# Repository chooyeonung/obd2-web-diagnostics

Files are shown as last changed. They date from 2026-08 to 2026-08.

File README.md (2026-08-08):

# ESP32 기반 차량 OBD-II 웹 진단 시스템

ESP32-S3 + CAN 트랜시버로 차량 OBD-II 포트에 연결하여, 브라우저(웹앱)에서 실시간 차량 진단(센서 모니터링, 고장코드 조회/소거)을 제공하는 시스템.

> **단계 전략**: ① 개인용 프로토타입 → ② 소량 검증(베타) → ③ 판매(제품화)
> 수익의 중심은 하드웨어가 아닌 **웹앱(서비스)**에 둔다. 통신 계층을 ELM327 표준으로 추상화해 "아무 동글이나 꽂아도 되는 진단 서비스"를 먼저 만들고, 자체 하드웨어는 프리미엄 옵션으로 추가한다.

---

## 1. 로드맵

### Phase 1 — 개인용 프로토타입 (지금)

목표: **내 차에서 내 웹앱으로 진단이 되는가?**

- [ ] 부품 구매 (아래 BOM)
- [ ] ELM327 호환 BLE 동글 1개 구매 (웹앱 선행 개발용, 쿠팡 1~3만 원 / 품질 원하면 vLinker MC+)
- [ ] 웹앱: Web Bluetooth로 동글 연결 → 표준 PID 조회(RPM, 냉각수온, 차속) 성공
- [ ] 하드웨어: 개발보드 + 모듈 결선(§4) → 벤치 테스트(CAN 루프백) → 차량 테스트
- [ ] 펌웨어: TWAI(CAN) 수신 → OBD-II 요청/응답 → WebSocket 전송
- [ ] 웹앱 트랜스포트 추상화: 동글(BLE)과 자작 보드(WebSocket) 모두에서 동일 동작 확인

### Phase 2 — 소량 검증 (10~50대)

목표: **다양한 차종에서 검증 + 커스텀 PCB화**

- [ ] KiCad로 아트웍 직접 설계 또는 크몽/설계사무소에 의뢰(2층, 부품 30~40개 → 설계비 약 30~80만 원)
- [ ] JLCPCB 등 PCBA로 소량 제작(이 수량대는 국내 턴키 대비 1/5~1/10 비용)
- [ ] WiCAN 공개 회로도를 전원부/보호회로 레퍼런스로 검토 (회로 참고 OK, 코드 복사 금지 — §7)
- [ ] 베타 사용자 확보: 차종별 진단 데이터 편차 수집 (이 사업의 실질 난이도)
- [ ] 절전 설계 검증: 딥슬립 + 전압 감시(배터리 방전 방지)

### Phase 3 — 판매 (제품화)

목표: **인증 통과 + 리스크 관리 + 양산**

- [ ] KC 전파인증(적합성평가): 완제품 기준 수백만 원. KC 인증된 ESP32-WROOM 모듈 사용으로 시험 범위 축소
- [ ] 배터리 방전 대책 최종화(대기전류 목표 < 1mA), ECU 영향 최소화(리스닝 우선 설계)
- [ ] 약관/면책 고지(차량 연결 기기 특성상 필수)
- [ ] 수백 대 이상 → 국내 턴키 업체(아이씨뱅큐, 샘플피씨비, 제이디앤테크놀로지 등) 견적 비교
- [ ] 펌웨어 라이선스 최종 점검(§7): GPL 코드 미포함 확인

---

## 2. BOM 및 구매처 (Phase 1)

| 부품 | 역할 | 구매처 | 확인가(2026-08) |
|---|---|---|---|
| ESP32-S3-WROOM-1 N8R2 개발보드 | MCU (TWAI/CAN 컨트롤러 내장, WiFi/BLE) | 디바이스마트 (VND032) | 약 14,850원 |
| SN65HVD230 CAN 모듈 (CJMCU-230) | CAN 트랜시버 (3.3V) | 제노몰 / 쿠팡 | 약 1,500~1,820원 |
| LM2596 DC/DC 모듈 (SZH-PWSD-001) | 차량 12V → 5V 강압 | 디바이스마트 | 약 1,650원 |
| SMAJ24A | 입력 서지(TVS) 보호 | 디바이스마트 | 약 1,925원 |
| OBD-II 16핀 Male 커넥터 | 차량 연결 | 쿠팡/네이버 국내배송 | 제품별 상이 |
| (추가) 폴리퓨즈 500mA~1A | 과전류 보호 | 디바이스마트 | 수백 원 |
| (추가) SS34 쇼트키 다이오드 | 역접속 보호 | 디바이스마트 | 수백 원 |
| (선택) PESD1CAN 또는 NUP2105L | CAN 라인 ESD 보호 | 디바이스마트 | 수백 원 |

### 부품별 주의사항

- **SN65HVD230 (CJMCU-230)**: 보드 위 **120Ω 종단저항(보통 R2)을 반드시 제거**할 것. 차량 CAN 버스는 이미 양단 종단되어 있음. 안 떼면 버스 임피던스가 무너져 통신 불안정/타 ECU 영향 가능.
- **LM2596**: 최대 입력 40V — 차량 로드덤프 서지에 마진이 빠듯하므로 SMAJ24A + 퓨즈 + 역접속 다이오드 필수. 무부하 대기전류가 수 mA라 **상시전원(핀 16)에 꽂아두면 배터리 방전 위험** → 장기적으로 저대기전류 레귤레이터 또는 딥슬립+하이사이드 스위치 검토.
- **OBD 커넥터**: "OBD2 16Pin **Male Plug + Shell + Solder/Terminal Pin**" 타입(차량 단자에 직결 + 후면 핀에 직접 배선). 단순 연장케이블 아님. 못 구하면 OBD2 연장케이블을 잘라 사용(테스터로 핀-선색 확인).

---

## 3. OBD-II 커넥터 핀맵 (사용 핀)

| OBD-II 핀 | 신호 | 연결 대상 |
|---|---|---|
| 4 | 섀시 GND | 공통 GND |
| 5 | 시그널 GND | 공통 GND (4번과 함께 묶음) |
| 6 | CAN-H (ISO 15765-4) | SN65HVD230 CANH |
| 14 | CAN-L (ISO 15765-4) | SN65HVD230 CANL |
| 16 | 배터리 +12V (상시) | 퓨즈 → 보호회로 → LM2596 IN |

나머지 핀(K-Line 7/15, J1850 2/10 등)은 Phase 1에서 미사용. CAN(ISO 15765-4)만으로 국내 2008년 이후 차량 대부분 커버(가솔린은 표준 PID 의무 구현).

---

## 4. 회로 결선도 (Phase 1, 모듈 조합)

```
OBD 16 (+12V) ──[폴리퓨즈 1A]──[SS34 ▶]──┬──[LM2596 IN+]
                                          │
                                     [SMAJ24A]   (단방향, 캐소드가 +12V 쪽)
                                          │
OBD 4,5 (GND) ────────────────────────────┴──[LM2596 IN-] ── 공통 GND

LM2596 OUT+ (5.0V로 조정) ──→ ESP32-S3 보드 5V(VIN) 핀
LM2596 OUT- ──→ GND

ESP32-S3 3V3 ──→ SN65HVD230 VCC (3.3V 전용 소자!)
ESP32-S3 GND ──→ SN65HVD230 GND

ESP32-S3 GPIO4 (TWAI TX) ──→ SN65HVD230 D (CTX)
ESP32-S3 GPIO5 (TWAI RX) ──→ SN65HVD230 R (CRX)

SN65HVD230 CANH ──→ OBD 6
SN65HVD230 CANL ──→ OBD 14
(선택) PESD1CAN을 CANH/CANL-GND 사이에 배치
```

### 결선 체크리스트

- [ ] LM2596 출력을 **부하 연결 전** 5.0V로 트리머 조정 (기본값이 높게 온다)
- [ ] SN65HVD230 모듈 120Ω 종단저항 제거 확인
- [ ] SMAJ24A 방향 확인 (단방향: 캐소드 밴드가 +12V 쪽)
- [ ] ESP32-S3에서 GPIO4/5는 TWAI에 자유 배치 가능(GPIO 매트릭스). 스트래핑 핀(GPIO0, 3, 45, 46)은 피할 것
- [ ] 차량 연결 전 벤치에서 12V 어댑터로 전원부 단독 검증
- [ ] (전압 감시용, 권장) 12V → 100k/10k 분압 → ESP32 ADC 핀: 시동 여부 감지(≈13.5V↑) 및 저전압 시 딥슬립

---

## 5. 펌웨어 아키텍처 (자체 작성)

> **처음부터 자체 작성한다.** wican-fw(GPL-3.0) 코드를 가져오면 제품화 시 소스 공개 의무 발생. Apache-2.0/MIT 스택만 사용(§7).

```
┌─────────────────────────────────────────┐
│  Web UI (LittleFS에 정적 파일로 탑재)      │
├─────────────────────────────────────────┤
│  HTTP 서버 + WebSocket (esp_http_server) │
│  WiFi SoftAP (초기) / STA (공유기 접속)    │
├─────────────────────────────────────────┤
│  ELM327 호환 명령 계층 (AT + PID 요청)     │  ← 웹앱과의 계약(contract).
├─────────────────────────────────────────┤     동글이든 자작보드든 동일 인터페이스
│  OBD-II 계층: SAE J1979 (Mode 01/03/04/09)│
│  ISO-TP (ISO 15765-2) 멀티프레임 조립      │
├─────────────────────────────────────────┤
│  TWAI 드라이버 (ESP-IDF, 500 kbps)        │
├─────────────────────────────────────────┤
│  전원 관리: ADC 전압 감시 → 딥슬립          │
└─────────────────────────────────────────┘
```

- 프레임워크: **ESP-IDF** (또는 Arduino-ESP32 코어) — 둘 다 Apache-2.0
- CAN 설정: 500 kbps, 11bit ID 기본(요청 0x7DF, 응답 0x7E8~0x7EF). 일부 차량 29bit(0x18DB33F1) 폴백
- 진단 기능 우선순위: Mode 01(실시간 데이터) → Mode 03(DTC 조회) → Mode 04(DTC 소거) → Mode 09(VIN)
- **웹앱 서빙은 ESP32에서 직접**(LittleFS): 외부 HTTPS 호스팅 시 브라우저 혼합 콘텐츠 정책으로 ws:// 연결이 차단됨
- 안전 원칙: 기본은 **수신 전용**에 가깝게, 전송은 표준 진단 요청만. 임의 CAN 주입 기능은 제품에서 제외

## 6. 웹앱 아키텍처

```
┌───────────────────────────────────────────────┐
│  UI: 대시보드(게이지/차트), DTC 목록·해설, 로그   │
├───────────────────────────────────────────────┤
│  도메인 계층: PID 디코딩 테이블(J1979),          │
│              DTC 데이터베이스(P0xxx 해설)        │
├───────────────────────────────────────────────┤
│  프로토콜 계층: ELM327 명령 생성/응답 파싱        │
├───────────────────────────────────────────────┤
│  트랜스포트 추상화 (인터페이스 1개, 구현 2개)      │
│   ├─ WebSocket  ← 자작 ESP32 보드              │
│   └─ Web Bluetooth(BLE) ← 시판 ELM327 동글      │
└───────────────────────────────────────────────┘
```

- **트랜스포트 추상화가 핵심**: Phase 1에서 동글로 개발한 코드가 자작 보드·WiCAN·향후 자체 제품까지 그대로 재사용됨
- Web Bluetooth는 Chrome/Edge 지원(iOS Safari 미지원 — iOS 대응 필요 시 WebSocket 경로 사용)
- 오프라인 대응: PWA(서비스워커)로 구성하면 지하주차장 등 무네트워크 환경에서도 동작
- 참고 프로젝트: EQM_OBDWEB(ESP32 웹 대시보드 서빙 사례), ELMduino(MIT, PID 파싱 참고), obd-ble-serial(BLE 연결 사례)

---

## 7. 라이선스 전략

| 자산 | 라이선스 | 사용 방침 |
|---|---|---|
| wican-fw 펌웨어 코드 | GPL-3.0 | **코드 복사/개조 금지** (제품화 시 소스 공개 의무 발생). 기능 아이디어 참고만 |
| WiCAN 회로도 (sch/) | GPL-3.0 (저장소) | 회로 토폴로지(설계 개념) 참고는 가능. 파일 자체를 복제·배포하지 않음. Phase 2에서 자체 설계로 재작성 |
| ESP-IDF / Arduino-ESP32 | Apache-2.0 / LGPL | 사용 OK |
| ELMduino | MIT | 사용 OK (파싱 로직 참고/포함 가능) |
| 자체 펌웨어·웹앱 | 자체 결정 | 비공개 유지 가능하도록 GPL 코드 미포함 원칙 유지 |

## 8. 인증·판매 리스크 체크리스트 (Phase 3)

- [ ] **KC 적합성평가(전파인증)**: WiFi/BLE 탑재 완제품은 필수. KC 인증 완료된 ESP32-WROOM 모듈 채택 시 시험 범위 축소되나 완제품 등록은 별도. 예산 수백만 원 단위
- [ ] **배터리 방전**: 상시전원 사용 시 대기전류 스펙 명시(목표 <1mA), 저전압 컷오프 필수
- [ ] **ECU 안전성**: 표준 진단 요청 외 전송 금지, DTC 소거는 사용자 확인 2단계
- [ ] **면책 고지**: 차량 보증/AS 관련 분쟁 대비 약관 명시
- [ ] **경쟁 구도**: 하드웨어 단품은 중국산 저가 동글과 가격 경쟁 불가 → 웹앱 구독/서비스 모델로 차별화
- [ ] **GPL 오염 검사**: 배포 전 펌웨어 의존성 라이선스 전수 확인

---

## 9. 참고 자료

- WiCAN (오픈소스 ESP32 OBD 동글): <https://github.com/meatpiHQ/wican-fw> — 회로 레퍼런스, GPL 주의
- WiCAN Pro (전 프로토콜 지원 상위판, $89): <https://www.crowdsupply.com/meatpi-electronics/wican-pro>
- ELMduino (MIT, ELM327/OBD 파싱): <https://github.com/PowerBroker2/ELMduino>
- EQM_OBDWEB (ESP32 웹 OBD 대시보드): <https://github.com/EQMOD/EQM_OBDWEB>
- obd-ble-serial (Web BLE 연결 예제): <https://github.com/vdvornichenko/obd-ble-serial>
- 국내 PCB/SMT: 아이씨뱅큐 <https://www.icbanq.com/pcb>, 샘플피씨비 <http://www.samplepcb.co.kr/>, PCB아트웍스 <https://pcbartworks.co.kr/>
- 해외 PCBA: JLCPCB <https://jlcpcb.com/>

---

*작성: 2026-08-08 · Phase 1 진행하며 실측값/차종 테스트 결과를 이 문서에 갱신할 것*

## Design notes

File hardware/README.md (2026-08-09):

# hardware/ — KiCad 회로도

`obd2-gateway.kicad_sch` — 벤치 회로(모듈 단위)의 KiCad 회로도.
KiCad 7 이상에서 열림 (독립 파일이라 프로젝트 없이 더블클릭으로 열려요).

- 연결은 **같은 이름의 부품 사이를 실제 배선(wire)으로 연결한 전통적 스타일 — 선을 따라가며 읽으면 됩니다
- 심볼은 자체 라이브러리(OBD2DIY)로 파일 안에 내장 — 별도 라이브러리 설치 불필요
- 향후 캐리어 보드 아트웍 시 이 회로도에 풋프린트를 지정하고 PCB로 넘기면 됨

kicad-cli 7.0.11로 파싱/SVG 출력 검증 완료.

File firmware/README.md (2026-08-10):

# OBD-II WiFi 게이트웨이 펌웨어 (ESP32-S3)

브라우저 ←WiFi/WebSocket→ **[이 펌웨어: ELM327 에뮬레이션]** ←CAN(TWAI)→ 차량 ECU

웹앱의 `WebSocketTransport`와 대화 규격이 맞춰져 있어, 플래시 후 웹앱에서
"자작 보드 (WiFi/WebSocket)" 트랜스포트로 바로 연결된다. Safari/iPhone도 이 경로로 커버.

## 결선 (구매 부품 기준)

| ESP32-S3 (VND018) | 연결 대상 |
|---|---|
| GPIO17 (J3 핀10) | SN65HVD230 **D** (CTX) |
| GPIO18 (J3 핀11) | SN65HVD230 **R** (CRX) |
| 3V3 | SN65HVD230 VCC |
| GND | SN65HVD230 GND, LM2596 OUT- |
| 5V(VIN) | LM2596 OUT+ (**5.0V로 조정 후 연결**) |

- SN65HVD230 CANH → OBD 6번 핀, CANL → OBD 14번 핀
- 전원: OBD 16번(+12V) → 폴리퓨즈 → SS34 → SMAJ24A/P6KE24A(병렬) → LM2596 IN+
- **CJMCU-230 모듈의 120Ω 종단저항(R2) 제거 필수**

## 빌드 & 플래시

[ESP-IDF 5.x](https://docs.espressif.com/projects/esp-idf/en/stable/esp32s3/get-started/) 설치 후 (VS Code ESP-IDF 확장 권장):

```bash
cd firmware
idf.py set-target esp32s3
idf.py build          # web/ 폴더가 LittleFS 이미지로 자동 포함됨
idf.py -p COM포트 flash monitor
```

## 사용

1. 부팅 후 WiFi **`OBD2-DIAG`** (비밀번호 `obd12345`) 접속
2. 브라우저에서 `http://192.168.4.1/` → 내장 테스트 콘솔 (ATZ, 010C 등 즉시 테스트)
3. 본 웹앱에서는 WebSocket 주소 `ws://192.168.4.1/ws` 로 연결

## 벤치 테스트 순서 (차량 연결 전)

1. USB 전원만으로 부팅 → WiFi 접속 → 콘솔에서 `ATZ` 응답 확인 (CAN 없이도 동작)
2. `010C` → CAN 미연결 상태면 `NO DATA` (정상 — 타임아웃 경로 확인)
3. 트랜시버 연결 + CAN 분석기(또는 두 번째 보드)로 루프백 응답 테스트
4. 차량 연결: OBD 커넥터 결선 후 `010C` → `41 0C xx xx` 응답 확인

## 구조

```
main/
  twai_bus.c   TWAI(CAN) 드라이버 — 500kbps, 0x7E8~0x7EF 수신 필터
  obd.c        ISO-TP 최소 구현 (SF 요청, SF/FF+CF 응답 조립, Flow Control)
  elm327.c     ELM327 호환 명령 파서 (AT 설정 + OBD hex 패스스루)
  wifi_ap.c    SoftAP (OBD2-DIAG / 192.168.4.1)
  ws_server.c  WebSocket(/ws) + LittleFS 정적 서빙(웹 콘솔)
web/           LittleFS로 플래시되는 정적 파일 (테스트 콘솔)
```

## TODO

- [ ] BLE(ELM327 에뮬레이션) 듀얼 모드 — 안드로이드/데스크톱 크롬 직결용
- [ ] ADC 전압 감시 (ATRV 실측값 + 저전압 딥슬립)
- [ ] STA 모드 설정 UI (공유기 접속 옵션)
- [ ] OTA 업데이트
- [ ] Blazor 웹앱 publish 산출물을 web/에 넣어 self-hosting (선택)

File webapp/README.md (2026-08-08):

# OBD-II 웹 진단 — Blazor WASM 웹앱

vLinker MC+ (ELM327 호환 BLE 동글) 또는 내장 시뮬레이터로 차량 진단을 수행하는 Blazor WebAssembly 앱.

## 실행 방법

```bash
cd webapp
dotnet run
```

브라우저에서 `http://localhost:5000` (콘솔에 표시되는 포트) 접속.

- **시뮬레이터 모드**: 동글/차량 없이 바로 동작. 가상 ECU가 주행 데이터와 고장코드(P0133, P0420)를 흉내낸다.
- **BLE 모드**: Chrome/Edge에서만 동작(Web Bluetooth). vLinker MC+ 전원이 켜진 상태(차량 OBD 포트 연결)에서 "연결" 클릭 → 기기 선택.
  - Web Bluetooth는 **HTTPS 또는 localhost**에서만 동작한다. 외부 배포 시 HTTPS 필수.

## 구조

```
Services/
  IObdTransport.cs      트랜스포트 추상화 (시뮬레이터/BLE/향후 WebSocket 공용 인터페이스)
  SimulatorTransport.cs 가상 ELM327+ECU (실차 없이 전체 흐름 테스트)
  BleTransport.cs       Web Bluetooth JS interop 래퍼
  Elm327Client.cs       ELM327 대화 규칙 (명령 → '>' 프롬프트까지 응답 수집, 초기화 시퀀스)
  ObdService.cs         고수준 진단 API (PID 스냅샷, DTC 조회/소거, VIN) + 응답 파서
  PidDefinitions.cs     SAE J1979 Mode 01 PID 테이블 (여기 추가하면 UI 자동 반영)
  DtcDecoder.cs         DTC 2바이트 → P/C/B/U 코드 + 한글 설명
wwwroot/js/obd-ble.js   Web Bluetooth 모듈 (프레임워크 독립 — 향후 ESP32용 경량 페이지에 재사용)
Pages/Home.razor        대시보드 (연결/게이지/DTC/통신 로그)
```

## 설계 노트

- **트랜스포트 추상화**가 핵심: 자작 ESP32 보드가 완성되면 `WebSocketTransport`를 `IObdTransport`로 추가하기만 하면 나머지 계층은 그대로 동작한다. ESP32 펌웨어가 ELM327 명령을 에뮬레이션하는 것이 전제.
- DTC 소거(Mode 04)는 되돌릴 수 없는 동작이라 2단계 클릭 확인을 거친다.
- 응답 파서는 실차의 흔한 변형(SEARCHING 프리픽스, 멀티라인 응답, ISO-TP 프레임 인덱스 `0:`, NO DATA)에 관대하게 동작하도록 작성했다.

## 다음 단계 (TODO)

- [ ] 실차(vLinker MC+)에서 BLE 연결·PID 폴링 검증
- [ ] Mode 02(프리즈 프레임), Mode 07(미확정 DTC) 추가
- [ ] 시계열 차트(주행 로그) 및 기록 저장
- [ ] PWA 구성(오프라인 동작)
- [ ] 자작 ESP32 보드용 WebSocketTransport 추가

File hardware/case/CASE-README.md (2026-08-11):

# OBD_CAN_ESP32_V2 케이스 (초안 v1)

외형 약 78.4 × 42.4 × 30mm · 상하 2피스 · M2.5 나사 4개로 리드+PCB+베이스 동시 체결

## 구조

- **베이스**: PCB가 나사 보스 4개(높이 8.5mm) 위에 안착. 뒷면 부품(D1·Q1·TP)과
  J1 커넥터 공간 확보. 오른쪽 벽에 J1 케이블 개구 + 커넥터 하우징 받침 턱
  (케이블을 뽑을 때 힘이 납땜부가 아닌 케이스에 걸리도록)
- **리드**: 분리면 = PCB 윗면. 오른쪽 벽에 USB-C 개구(데브킷 플래시/디버깅용),
  상단에 벅 컨버터 방열 슬롯 + **RGB LED 상태표시 창**(⌀5, 바깥으로 벌어지는
  원뿔형이라 비스듬히 봐도 보임). 나사 기둥이 PCB를 위에서 눌러 고정
- LED 색 규칙(펌웨어): 파랑 숨쉬기=대기, 초록 깜빡=통신, 주황=CAN오류, 보라=OTA
- **왼쪽 내부 5mm 여유**: 데브킷 WROOM 안테나 돌출 공간 (금속 부착 금지)
- 조립: M2.5 × 25mm 접시머리 나사 4개가 리드 → PCB 구멍(2.7mm) → 베이스 보스(셀프태핑) 순으로 관통

## 실측 후 조정할 파라미터 (obd2_case.scad 상단)

| 파라미터 | 현재값(추정) | 실측 방법 |
|---|---|---|
| `H_BOT` | 8.5 | 보드 뒷면에서 J1 하우징 바닥까지 + 1mm |
| `H_TOP` | 16 | PCB 윗면에서 데브킷 최고점(USB 커넥터)까지 + 2mm |
| `USB_Z0`/`USB_Z1` | 9.5/15.5 | PCB 윗면 기준 데브킷 USB-C 상하 위치 |
| `USB_Y0`/`USB_Y1` | 7/29 | 두 USB-C 포트의 좌우 범위 |
| `LED_X`/`LED_Y` | 52/17.5 | 데브킷 RGB LED 위치 (보드 좌하단 기준). 데브킷 장착 후 위에서 내려다보며 실측 |

값 수정 → OpenSCAD에서 열기 → part="base"/"lid"로 각각 STL 내보내기.

## 출력 가이드

- 재질: **PETG / ABS / PA12(나일론)** — 차량 실내 온도 때문에 PLA 금지
- 방향: 베이스·리드 모두 개구부가 위로 오게(뒤집힌 상태 그대로) 출력, 서포트 불필요
  (USB/J1 개구는 브리지 15mm 이하라 서포트 없이 출력됨)
- 레이어 0.2mm, 벽 3라인, 인필 20%+
- JLC3DP 주문 시: PA12(MJF) 회색 권장

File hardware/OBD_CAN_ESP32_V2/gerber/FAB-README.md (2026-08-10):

# OBD_CAN_ESP32_V2 — 발주 안내

## 보드 사양 (JLCPCB 주문 시 입력값)

| 항목 | 값 |
|---|---|
| 치수 | 64 × 36 mm |
| 층수 | 2 |
| 두께 | 1.6 mm |
| 구리 두께 | 1 oz |
| 표면처리 | HASL(무연) 또는 ENIG |
| 최소 트랙/간격 | 0.20 / 0.20 mm |
| 최소 드릴 | 0.20 mm (U2 열비아 6개, 패드경 0.50 mm) |
| 비아 | 0.60 / 0.30 mm |
| 나사구멍 | 2.7 mm NPTH × 4 (M2.5) |
| 총 홀 수 | 83 |
| 안테나 구리 금지 | 왼쪽 끝 5mm 폭 (양면) — 데브킷 WROOM 안테나 하부 |

## 파일 구성

| 파일 | 용도 |
|---|---|
| `*-F_Cu.gbr` / `*-B_Cu.gbr` | 앞면/뒷면 구리 |
| `*-F_Mask.gbr` / `*-B_Mask.gbr` | 솔더마스크 |
| `*-F_Silkscreen.gbr` / `*-B_Silkscreen.gbr` | 실크스크린 |
| `*-Edge_Cuts.gbr` | 보드 외형 |
| `*.drl` | 드릴 (PTH/NPTH 병합, 엑셀론) |
| `*-job.gbrjob` | 거버 잡 파일 |
| `BOM-jlcpcb.csv` | 부품 목록 (LCSC 번호 포함) |
| `CPL-jlcpcb.csv` | 부품 좌표 (SMT 조립 주문 시) |
| `*-top-pos.csv` / `*-bottom-pos.csv` | KiCad 원본 좌표 파일 |

## 발주 순서

1. jlcpcb.com → **Order now** → 위 zip 업로드
2. 미리보기에서 64×36mm, 2층, 앞/뒷면 패턴 확인
3. 층수 2 / 두께 1.6 / 표면처리 선택
4. **직접 납땜하는 경우: SMT 조립 끄기** → 여기서 끝
5. SMT 조립을 맡기는 경우 → BOM·CPL 업로드 → 부품 확인 화면에서 회전값 검토

## 주문 전 확인할 것

- **Q1 부품 확정**: 회로도 값이 `Q_PMOS_GDS`(범용 심볼)입니다. BOM에는 SUD50P06-15-GE3(C141584)을 넣어뒀습니다. 저렴한 대안은 HYG120P06LR1D(C2844410). 회로도 값도 실제 품번으로 바꿔두세요.
- **R3는 실장 금지(DNP)**: 차량 CAN 버스에 이미 종단저항이 있습니다. CPL에서 제외했습니다.
- **J3/J4 헤더**: 데브킷을 꽂을 암헤더(2.54mm 1×22) 2개는 BOM에 품번을 넣지 않았습니다. 직접 구매하세요.
- **D1(SM8S24A) 재고**: LCSC 재고가 1,000개 미만이고 제조사별로 가격이 3배까지 차이납니다. 주문 시점에 확인 필요.
- **R12(182k) 재고**: 모든 소스가 5,000개 미만입니다. 부족하면 C163428(Yageo) 또는 180k로 대체 가능(스위칭 주파수 약 505kHz로 미세 변동).
- **L1 Isat 3.5A**: 계획서에는 4A로 적었지만 실제 부하는 0.8A 이하이므로 충분합니다.

## 조립 시 참고

- 부품 위치는 `docs/assembly-front.svg` / `docs/assembly-back.svg` 참조 (실크스크린에 참조번호가 없습니다)
- 뒷면 대형 부품(D1 TVS, Q1 MOSFET, J1 커넥터)을 먼저, 앞면 SMD를 나중에
- U2 열패드는 뒷면 열비아 6개를 통해 인두로 납을 흘려넣을 수 있습니다
- **J1 커넥터 몸통이 보드 오른쪽으로 6.8mm 돌출**합니다. 케이스에서 몸통을 받쳐주도록 설계하세요.

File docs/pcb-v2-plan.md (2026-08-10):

# PCB V2 계획 — C안: 온보드 벅 + 데브킷 하부 배치 (목표 66×36mm)

V1(69×72) 대비 면적 −56%. 핵심: LM2596 모듈 제거 → SMD 벅 회로, 모든 SMD를 데브킷 아래(헤더 사이 22.86mm 폭, 높이 여유 ~8.5mm)로.

## 1. 벅 컨버터 회로 (LM2596 모듈 대체)

**IC: TI TPS54360B** (SO-8 PowerPAD) — 입력 4.5~**60V**, 3.5A, 비동기 벅.
60V 내압이라 SM8S24A 클램핑 전압(~39V)과 로드덤프에 마진 충분. LCSC/JLC 재고 안정.

| Ref | 값/부품 | 패키지 | 비고 |
|---|---|---|---|
| U2 | TPS54360BDDA | SO-8 PowerPAD | 열패드 → GND 비아 4개 이상 |
| C10,C11 | 2.2µF 100V X7R ×2 | 1210 | VIN 입력 (VBAT_PROTECTED) |
| C12 | 100nF 100V | 0805 | VIN 고주파 |
| C13 | 100nF 25V | 0603 | BOOT–SW |
| D10 | B360A (60V 3A 쇼트키) | SMA | 캐치 다이오드, SW–GND |
| L1 | 10µH 4A 실드형 (예: SWPA6045S100MT) | 6.0×6.0×4.5mm | SW → VOUT |
| C14,C15 | 22µF 16V X7R ×2 | 1206 | 출력 (+5V) |
| R10 | 52.3kΩ 1% | 0603 | FB 상단 (VOUT→FB) |
| R11 | 10.0kΩ 1% | 0603 | FB 하단 (FB→GND) → 5.0V |
| R12 | 182kΩ 1% | 0603 | RT/CLK → GND, fsw≈500kHz |
| R13 | 8.06kΩ | 0603 | COMP 직렬 R |
| C16 | 3300pF | 0603 | COMP 직렬 C (R13와 직렬로 COMP→GND) |
| R14/R15 | 365k / 88.7k (선택) | 0603 | EN 분압 — UVLO ≈8.6V 시작 (크랭킹 채터 방지). 생략 시 EN 플로팅 |

- 배선: VIN 루프(C10/C11–IC–D10) 최소화, SW 노드 면적 최소, FB 트레이스는 L/SW에서 멀리
- VOUT(+5V) → 데브킷 5V 핀(J3-21), 부하 여유: ESP32 WiFi 피크 ~0.6A ≪ 3.5A
- 점유 면적 ≈ 18×16mm → 데브킷 하부 수납 가능 (최대 높이 L1 4.5mm < 8.5mm)

## 2. 보드 구성 (66×36)

```
 ← 66mm →
┌────────────────────────────────────────────┐
│ [안테나 돌출/구리금지 8mm]   ESP32-S3 DevKitC   [USB 엣지] │ ↑
│ ┌헤더row───────────────────────헤더row┐      │ 36mm
│ │  (하부) CAN존 │ 벅존 │ 입력보호존        │      │
│ └──────────────────────────────────┘      │
│ [JST-XH 6P]  [TP열 1.5mm]                  │ ↓
└────────────────────────────────────────────┘
```

- **데브킷 방향**: 안테나(WROOM 끝) = 보드 왼쪽 **엣지 밖으로 2~3mm 돌출** 또는 그 영역 전층 구리 금지. USB 커넥터 = 오른쪽 엣지에 맞춤(케이블 접근)
- **하부 존 배치** (모두 높이 ≤4.5mm라 간섭 없음):
  - 입력보호존(USB쪽 끝): F1(1812) → SM8S24A → Q1(TO-252) + R1 + D2
  - 벅존(중앙): 위 1번 회로
  - CAN존(커넥터쪽): U1 + C1(U1 VCC 2mm 이내!) + R2 + R3(DNP)
- **커넥터**: 터미널블록 → **JST-XH 6P 사이드엔트리**(S6B-XH-A, 16.5×7mm) 하단 긴 변 엣지. D3(NUP2105L)는 커넥터 3mm 이내
- **TP**: D1.5mm SMD 패드로 축소, 하단 스트립에 일렬
- CAN_H/L: 차동 페어로 커넥터→D3→U1 최단 라우팅, 스터브 최소

## 3. V1에서 가져갈 수정사항

- [ ] **D2 제너 180° 반전** (K→VBAT_PROTECTED/소스, A→게이트) — V1 치명 이슈
- [ ] C1을 U1 VCC 핀 옆으로
- [ ] CAN_TX/RX = J3 핀10/11 = **GPIO17/GPIO18** (DevKitC-1 공식 핀맵 기준 — 실물 실크로 최종 확인)
  → 펌웨어 `twai_bus.h` GPIO17/18로 변경 완료. 모든 문서도 17/18로 통일함

## 4. 발주 체크 (JLCPCB 기준)

- 2층, 1oz, 보드 66×36, 최소 트랙/갭 0.2mm면 충분
- TPS54360B·B360A·인덕터는 LCSC 파트넘버로 BOM 지정 (SMT 조립 시)
- 데브킷 헤더는 스루홀 → 이코노미 SMT + 수납땜 또는 스탠다드 조립

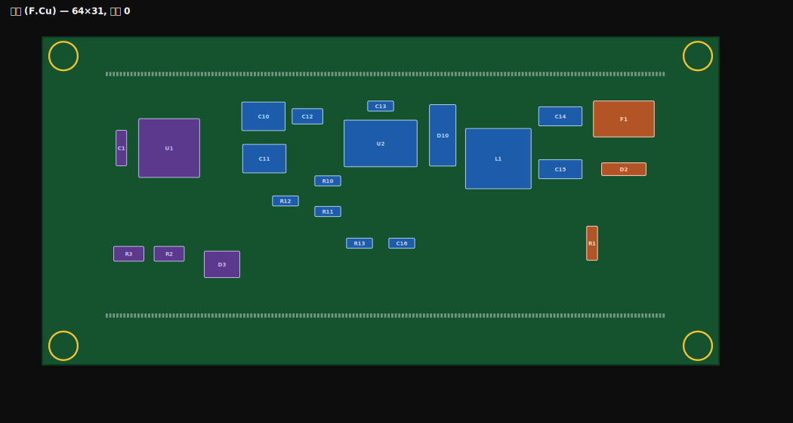
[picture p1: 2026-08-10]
hardware/OBD_CAN_ESP32_V2/front-preview.png

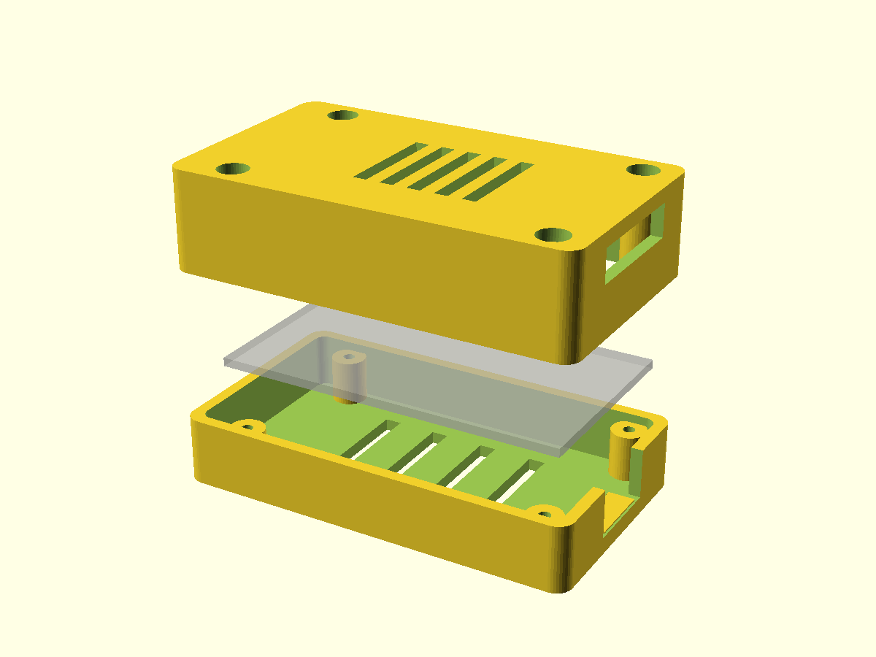
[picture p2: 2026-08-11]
hardware/case/preview_exploded.png

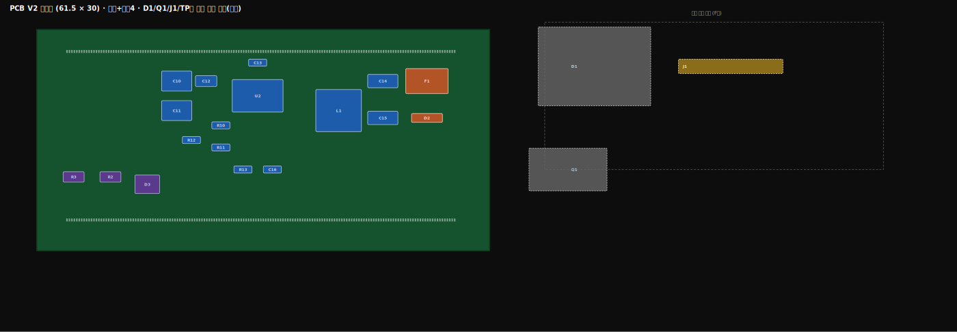
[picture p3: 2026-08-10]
hardware/OBD_CAN_ESP32_V2/placement-preview.png

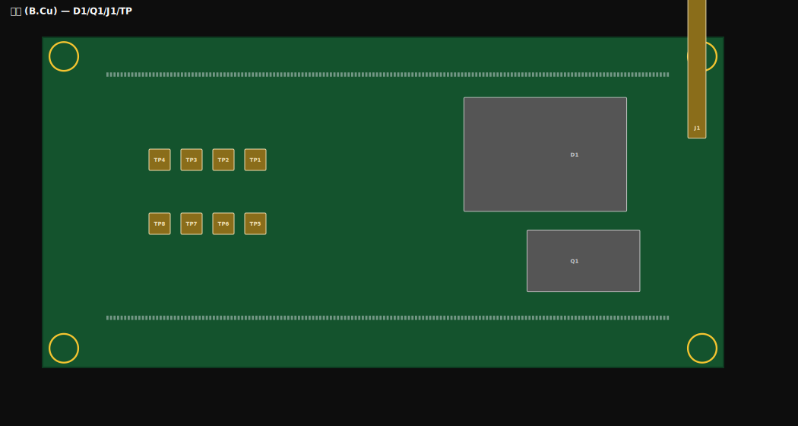
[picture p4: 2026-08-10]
hardware/OBD_CAN_ESP32_V2/back-preview.png

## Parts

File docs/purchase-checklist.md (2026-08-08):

# Phase 1 부품 구매 체크리스트

작성일: 2026-08-08 · 예상 총 예산: **약 3~4만 원** (+ ELM327 동글 1~3만 원)

## 디바이스마트 (한 번에 주문)

| # | 부품 | 검색 키워드 | 수량 | 단가(참고) | 확인 포인트 |
|---|---|---|---|---|---|
| ☐ | ESP32-S3 개발보드 | `ESP32-S3-WROOM-1 N8R2` (상품코드 VND032) | 1 | 약 14,850원 | N8R2(8MB Flash/2MB PSRAM) 맞는지, USB-C 2포트(USB/UART) 타입 권장 |
| ☐ | LM2596 DC/DC 모듈 | `LM2596 SZH-PWSD-001` | 2 | 약 1,650원 | **가변(트리머)형**인지 확인 — 고정 3.3V/5V 출력형 아님 |
| ☐ | SMAJ24A TVS | `SMAJ24A` | 5 | 약 1,925원/개 또는 소포장 | **단방향(uni)** 확인. 최소구매수량 체크 |
| ☐ | 폴리퓨즈 1A | `폴리퓨즈 1A 리드타입` | 5 | 수백 원 | 정격전압 30V 이상 (예: RXEF 시리즈) |
| ☐ | 쇼트키 다이오드 | `SS34` 또는 `1N5822` | 5 | 수백 원 | 3A/40V급, 역접속 보호용 |
| ☐ | (선택) CAN ESD 보호 | `PESD1CAN` 또는 `NUP2105L` | 2 | 수백 원 | SOT-23 SMD라 변환기판 필요할 수 있음 — 없으면 생략 가능 |
| ☐ | 소모품 | 점퍼선(F-F/M-F), 만능기판, 수축튜브, 2.54mm 핀헤더 | — | ~5,000원 | 없으면 같이 주문 |

## 제노몰

| # | 부품 | 검색 키워드 | 수량 | 단가(참고) | 확인 포인트 |
|---|---|---|---|---|---|
| ☐ | SN65HVD230 CAN 모듈 | `SN65HVD230 CAN Module` | **2~3** | 약 1,500원 | 보드 사진에서 **120Ω 저항(R2) 위치 확인**(도착 후 제거해야 함). 예비 포함 2~3개 권장 |

배송비 고려해서 SN65HVD230도 쿠팡(약 1,820원)으로 합쳐도 무방 — 합계 차이는 몇백 원.

## 쿠팡 / 네이버쇼핑

| # | 부품 | 검색 키워드 | 수량 | 확인 포인트 |
|---|---|---|---|---|
| ☐ | OBD-II Male 커넥터 | `OBD2 16핀 male 커넥터 납땜` / `OBD2 male plug 하우징 터미널` | **2** | 아래 "OBD 커넥터 고르는 법" 필독 |
| ☐ | ELM327 BLE 동글 (웹앱 선행 개발용) | `vLinker MC+` (권장) 또는 `ELM327 v1.5 블루투스 4.0` | 1 | **BLE(블루투스 4.0+) 필수** — Web Bluetooth는 클래식 BT 미지원. iOS 지원 표기 = BLE라는 신호 |

### OBD 커넥터 고르는 법 (잘못 사면 잘라서 배선해야 함)

사진에서 반드시 확인:

1. **Male(수) 커넥터** — 차량 포트에 꽂히는 쪽. 사다리꼴 16핀 돌출형
2. **뒷면이 열리는 하우징(Shell)** + **납땜 가능한 터미널 핀** 구성 — "플러그 + 쉘 + 솔더핀" 세트
3. 케이블이 이미 몰딩된 일체형(연장케이블류)은 ✗ — 이건 잘라야 함
4. 대안: 검색어 `OBD2 커넥터 조립식` / `OBD2 male DIY 커넥터`
5. 정 못 찾으면 차선책으로 OBD2 연장케이블(수-암)을 사서 절단 — 테스터로 핀 4,5,6,14,16 대응 선색 확인

### ELM327 동글 참고

- 최우선: **vLinker MC+** (FORScan 등에서 검증된 안정성, 3만 원대) — 국내 재고 없으면 알리익스프레스
- 차선: 국내배송 "ELM327 V1.5 PIC18F25K80 블루투스 4.0 (BLE)" 표기 제품 — V2.1 표기나 칩 미표기 초저가는 호환성 문제 잦음
- 용도: 자작 보드 완성 전까지 웹앱(Web Bluetooth) 개발·차량 테스트용

## 주문 후 도착하면

- [ ] SN65HVD230 모듈 120Ω 저항(R2) 인두로 제거
- [ ] LM2596 무부하 상태에서 12V 입력 → 출력 5.0V로 트리머 조정
- [ ] 벤치(12V 어댑터)에서 전원부 단독 검증 후 차량 연결

---
*가격은 2026-08 확인 기준. 재고/가격 변동 시 이 문서 갱신*

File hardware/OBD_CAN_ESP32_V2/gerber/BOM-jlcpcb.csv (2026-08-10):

Comment | Designator | Footprint | LCSC Part # | 비고
TPS54360BDDAR | U2 | SOIC-8-EP (HSOP-8) | C524806 | 60V 3.5A 벅 컨트롤러
SN65HVD230DR | U1 | SOIC-8 | C12084 | 3.3V CAN 트랜시버
B360A | D10 | SMA / DO-214AC | C94193 | 60V 3A 쇼트키 (캐치 다이오드)
SM8S24A | D1 | DO-218AB | C314439 | 24V 자동차용 TVS (단방향)
MMSZ12T1G | D2 | SOD-123 | C72599 | 12V 제너 500mW (게이트 클램프)
NUP2105LT1G | D3 | SOT-23 | C14486 | CAN 라인 보호
SUD50P06-15-GE3 | Q1 | TO-252 (DPAK) | C141584 | P-ch MOSFET -60V 15mR (역접속 보호)
1812L110/33MR | F1 | 1812 | C142747 | PTC 1.1A 33V
SWPA6045S100MT | L1 | 6.0x6.0x4.5mm | C79272 | 10uH Isat 3.5A
S6B-XH-A(LF)(SN) | J1 | JST XH 6P 측면형 | C157919 | OBD 케이블 입력
2.2uF 100V X7R | C10,C11 | 1210 | C153036 | 벅 입력 커패시터
100nF 100V X7R | C12 | 0805 | C28233 | VIN 고주파 (Basic)
100nF 50V X7R | C13 | 0603 | C14663 | BOOT-SW (Basic)
100nF 50V X7R | C1 | 0805 | C49678 | U1 VCC 디커플 (Basic)
22uF 25V X5R | C14,C15 | 1206 | C12891 | 벅 출력 (Basic)
3300pF 50V X7R | C16 | 0603 | C1613 | COMP (Basic)
52.3k 1% | R10 | 0603 | C23198 | FB 상단
10.0k 1% | R11 | 0603 | C25804 | FB 하단 (Basic)
182k 1% | R12 | 0603 | C22894 | RT/CLK — 재고 적음, C163428 대체 가능
8.06k 1% | R13 | 0603 | C23112 | COMP 직렬 R
100k | R1 | 0805 | C149504 | 게이트 풀다운 (Basic)
0R jumper | R2 | 0805 | C17477 | 섀시-시그널 GND 연결 (Basic)
120R ** DNP ** | R3 | 0805 | C17437 | 실장 금지 — 차량 버스에 종단 있음
PinHeader 1x22 2.54mm | J3,J4 | THT 1x22 | - | 데브킷 수납용 — 암헤더 또는 핀헤더 별도 구매
Test pad (구리만) | TP1~TP8 | D2.0mm 패드 | - | 부품 없음
M2.5 나사구멍 | H1~H4 | 2.7mm NPTH | - | 부품 없음

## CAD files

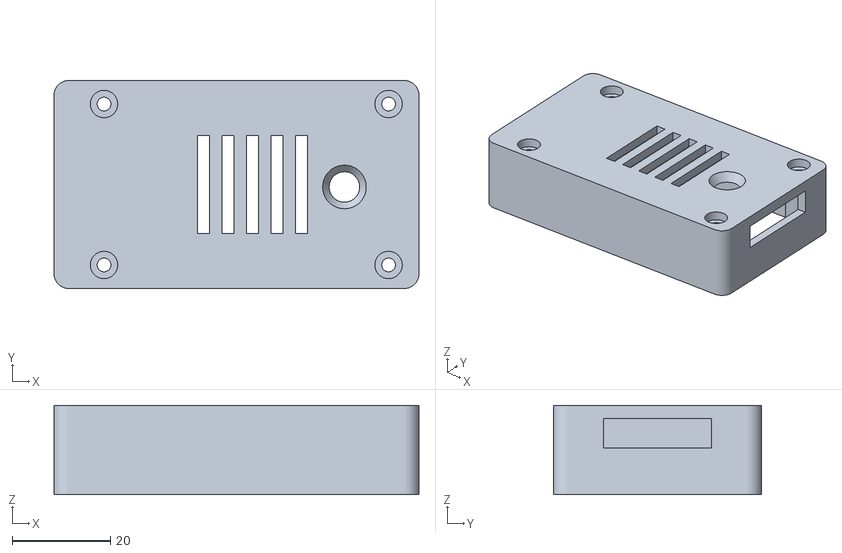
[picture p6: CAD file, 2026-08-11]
hardware/case/obd2_case_lid.stl
74.4 x 42.4 x 18.2

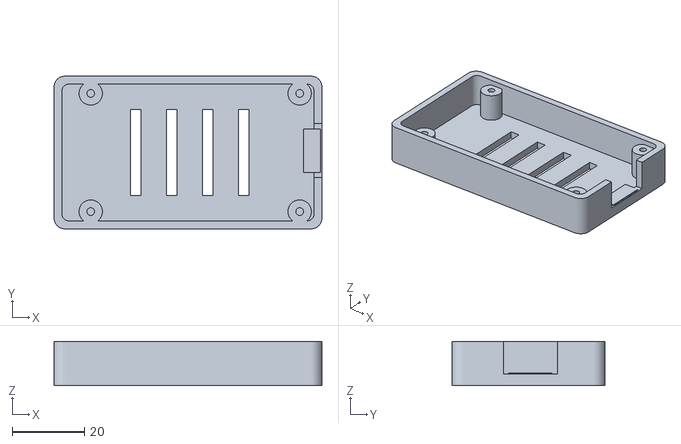
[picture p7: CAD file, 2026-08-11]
hardware/case/obd2_case_base.stl
74.4 x 42.4 x 12.3

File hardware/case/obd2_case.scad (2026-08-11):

// ============================================================
// OBD_CAN_ESP32_V2 케이스 (파라메트릭 초안)
// 좌표계: 보드 좌하단 = (0,0). X0=안테나(왼쪽), X64=J1/USB(오른쪽)
// ============================================================

/* ----- 실측 후 조정할 파라미터 (TBD) ----- */
H_BOT   = 8.5;   // PCB 아랫면 여유 (J1 하우징 ~7mm + 여유) [실측 확인]
H_TOP   = 16;    // PCB 윗면 여유 (소켓+데브킷+USB 상단) [실측 확인]
USB_Z0  = 9.5;   // PCB 윗면 기준 USB 개구 시작 높이 [실측 확인]
USB_Z1  = 15.5;  // USB 개구 끝 높이 [실측 확인]
LED_X   = 52;    // 데브킷 RGB LED 위치 X [실측 확인 — 데브킷 USB쪽 끝 근처]
LED_Y   = 17.5;  // 데브킷 RGB LED 위치 Y [실측 확인]
LED_D   = 5;     // LED 창 지름

/* ----- 보드 데이터 (PCB에서 추출한 고정값) ----- */
BW = 64;  BH = 36;  PCB_T = 1.6;
holes = [[3,1.6],[61,1.6],[3,34.4],[61,34.4]];   // M2.5 (2.7mm NPTH)
// J1 (XH 6P, 뒷면, +X로 케이블): kicad y99~111.5 → local Y 12.5~25
J1_Y0 = 11;  J1_Y1 = 26;
// 데브킷: Y 4.7~30.1 폭, USB는 +X 방향 오른쪽 끝
USB_Y0 = 7;  USB_Y1 = 29;
// 안테나: X0 왼쪽으로 ~3mm 돌출
ANT_GAP = 5;     // 왼쪽 내부 여유

/* ----- 케이스 파라미터 ----- */
WALL = 2.2;      // 벽 두께
GAP  = 1.0;      // 보드 주변 여유 (좌측 제외)
R    = 3;        // 외곽 라운드
FLOOR = 2.2;  ROOF = 2.2;
BOSS_D = 6.5;  BOSS_HOLE = 2.15;   // M2.5 셀프태핑
PILLAR_HOLE = 2.8;                  // 리드 관통(스크류 통과)
CBORE_D = 5.6;  CBORE_H = 2.5;      // 접시머리 카운터보어

/* ----- 파생 치수 ----- */
IX0 = -ANT_GAP;          IX1 = BW + GAP;     // 내부 X범위
IY0 = -GAP;              IY1 = BH + GAP;
OX0 = IX0-WALL; OX1 = IX1+WALL; OY0 = IY0-WALL; OY1 = IY1+WALL;
PCB_Z = FLOOR + H_BOT;                        // PCB 아랫면 z
TOP_Z = PCB_Z + PCB_T + H_TOP;                // 내부 상단 z
LID_SPLIT = PCB_Z + PCB_T;                    // 분리면 = PCB 윗면

$fn = 40;

module rbox(x0,y0,x1,y1,h,r) {  // 라운드 사각 기둥
  hull() for (p=[[x0+r,y0+r],[x1-r,y0+r],[x0+r,y1-r],[x1-r,y1-r]])
    translate([p[0],p[1],0]) cylinder(h=h, r=r);
}

/* ============ 베이스 (하부) ============ */
module base() {
  difference() {
    rbox(OX0,OY0,OX1,OY1, FLOOR+H_BOT+PCB_T, R);
    // 내부 공동
    translate([0,0,FLOOR]) rbox(IX0,IY0,IX1,IY1, H_BOT+PCB_T+1, R-WALL/2);
    // J1 케이블 개구 (PCB 아래, 오른쪽 벽)
    translate([IX1-0.1, J1_Y0, FLOOR+1])
      cube([WALL+2, J1_Y1-J1_Y0, H_BOT+PCB_T]);
    // 바닥 통풍 슬롯
    for (i=[0:3]) translate([14+i*10, 6, -1]) cube([3, BH-12, FLOOR+2]);
  }
  // 나사 보스 (PCB 지지)
  for (h=holes) translate([h[0],h[1],FLOOR])
    difference() {
      cylinder(d=BOSS_D, h=H_BOT);
      translate([0,0,-1]) cylinder(d=BOSS_HOLE, h=H_BOT+2);
    }
  // J1 하우징 받침 턱 (커넥터 몸통 아래 지지)
  translate([BW-2, J1_Y0+1.5, FLOOR]) cube([GAP+WALL+2-0.4, J1_Y1-J1_Y0-3, H_BOT-7.2]);
}

/* ============ 리드 (상부) ============ */
module lid() {
  difference() {
    union() {
      rbox(OX0,OY0,OX1,OY1, ROOF + H_TOP, R);
    }
    // 내부 공동
    translate([0,0,-1]) rbox(IX0,IY0,IX1,IY1, H_TOP+1, R-WALL/2);
    // USB 개구 (오른쪽 벽, PCB 위)
    translate([IX1-0.1, USB_Y0, USB_Z0])
      cube([WALL+2, USB_Y1-USB_Y0, USB_Z1-USB_Z0]);
    // LED 창 (데브킷 RGB LED 위, 원뿔형으로 벌어짐)
    translate([LED_X, LED_Y, H_TOP-1])
      cylinder(d1=LED_D, d2=LED_D+2*(ROOF+1)*0.8, h=ROOF+2);
    // 상단 통풍 슬롯 (벅 컨버터 상부: X 20~45)
    for (i=[0:4]) translate([22+i*5, 8, H_TOP-1]) cube([2.5, BH-16, ROOF+2]);
    // 나사 관통 + 카운터보어
    for (h=holes) translate([h[0],h[1],0]) {
      translate([0,0,-1]) cylinder(d=PILLAR_HOLE, h=H_TOP+ROOF+2);
      translate([0,0,H_TOP+ROOF-CBORE_H]) cylinder(d=CBORE_D, h=CBORE_H+1);
    }
  }
  // 나사 기둥 (리드→PCB까지 내려옴)
  for (h=holes) translate([h[0],h[1],0])
    difference() {
      cylinder(d=BOSS_D, h=H_TOP);
      translate([0,0,-1]) cylinder(d=PILLAR_HOLE, h=H_TOP+2);
    }
}

/* ============ 출력 선택 ============ */
part = "assembly";   // base | lid | assembly | exploded

if (part=="base") base();
if (part=="lid") lid();
if (part=="assembly") {
  base();
  translate([0,0,LID_SPLIT]) lid();
  // PCB 시각화 (초록)
  %translate([0,0,PCB_Z]) cube([BW,BH,PCB_T]);
}
if (part=="exploded") {
  base();
  translate([0,0,LID_SPLIT+28]) lid();
  %translate([0,0,PCB_Z+12]) cube([BW,BH,PCB_T]);
}

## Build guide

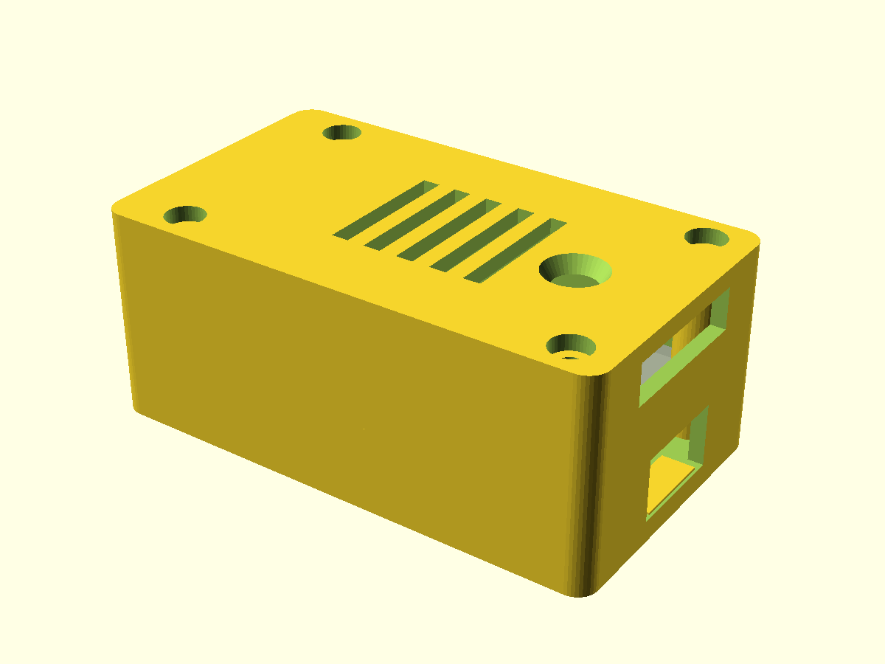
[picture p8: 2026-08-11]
hardware/case/preview_assembly.png

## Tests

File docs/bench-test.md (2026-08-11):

# 보드 첫 통전 & 검증 절차서 (V2 PCB 기준)

> 구판(만능기판+모듈 벤치)은 폐기. 이 문서는 JLCPCB 조립 보드 기준이다.
> **원칙: 각 단계를 통과하기 전에는 다음 단계로 넘어가지 않는다.**

## 준비물

- 조립된 V2 보드, ESP32-S3-DevKitC-1-N8R8, 멀티미터
- 12V 전원 (어댑터 1A 이상, 또는 차량)
- 손납땜 부품: Q1(FET), J1(XH 커넥터), 핀헤더소켓 2개, D1(TVS — 상시 운용 전 필수)
- 인두 + 실납 + 플럭스

## 0단계 — 손납땜 (통전 전)

- [ ] 핀헤더소켓 1×22 두 개를 J3/J4에 납땜 (데브킷을 소켓에 꽂은 채 위치 맞춰 납땜하면 정렬이 쉬움 — 단, 납땜 중 데브킷 과열 주의, 양끝 핀만 먼저)
- [ ] Q1 납땜: 탭(드레인)이 보드 패드 방향. 플럭스 바르고 다리 → 탭 순서
- [ ] J1 납땜 (스루홀)
- [ ] D1은 이 단계에서 생략 가능 (실차 상시 운용 전에는 필수 장착)
- [ ] 육안 검사: 브리지/냉납, 특히 Q1 주변

## 1단계 — 전원부 단독 (데브킷 꽂지 말 것!)

- [ ] 멀티미터 도통 모드: TP6(GND)–TP4(+5V) 간 단락 아닌지 확인 (삐 소리 나면 중단)
- [ ] J1으로 12V 인가 (XH 하네스 1·2번 = VBAT/GND — 조립도면 참조)
- [ ] TP1 (VBAT_OBD) ≈ 12V
- [ ] TP2 (VBAT_FUSED) ≈ 12V (F1 통과)
- [ ] TP3 (VBAT_PROT) ≈ 12V보다 0~0.3V 낮음 (Q1 통과 — 0V면 Q1 방향/납땜 확인)
- [ ] **TP4 (+5V) = 5.0V ± 0.15V** ← 벅 컨버터 첫 실증 포인트
- [ ] U2·L1 발열 확인 (무부하에서 미지근 이하)
- [ ] 12V를 역극성으로 인가 → TP3 = 0V (역접속 보호 동작) → 원상복구
- [ ] 10분 방치 후 재측정

## 2단계 — 데브킷 단독 (보드와 분리, USB만)

- [ ] USB-C로 PC 연결, `idf.py set-target esp32s3 && idf.py build flash monitor`
- [ ] 로그: `SoftAP started`, `HTTP/WS server started`
- [ ] WiFi `OBD2-DIAG`(pw `obd12345`) 접속 → `http://192.168.4.1/` 콘솔
- [ ] `ATZ` → `ELM327 v1.5 (OBD2-DIY)` / `010C` → `NO DATA` (CAN 미연결이므로 정상)

## 3단계 — 결합 (USB 분리 상태에서)

- [ ] 데브킷을 소켓에 장착 (안테나가 보드 왼쪽 밖을 향하도록 = USB 커넥터가 오른쪽)
- [ ] TP5 (+3V3) ≈ 3.3V 확인
- [ ] J1으로 12V 인가 → 부팅·WiFi·콘솔 재확인
- [ ] 12V 입력 전류 확인 가능하면 50~150mA 수준
- [ ] ⚠️ USB와 12V 동시 인가 금지

## 4단계 — 실차

- [ ] OBD 커넥터 배선: 16(+12V)→하네스 VBAT, 4·5(GND)→GND, 6(CAN-H)→TP7 라인, 14(CAN-L)→TP8 라인 (핀맵은 docs/wiring-guide.svg)
- [ ] 시동 OFF·키 ON에서 연결 → `ATZ` 확인
- [ ] `0100` → `41 00 ...` = 차량 통신 성공 🎉
- [ ] `010C`(RPM)·`0105`(수온)·`0902`(VIN) → 시동 후 RPM 변화 확인
- [ ] 웹앱 https://chooyeonung.github.io/obd2-web-diagnostics/ → 자동 감지 → 대시보드 동작

## 문제 발생 시

| 증상 | 우선 확인 |
|---|---|
| TP4가 0V | TP3부터 역추적 (F1? Q1?), U2 납땜 |
| TP4가 5V 아님 | R10/R11 값, FB 배선 — 측정값 알려주면 원인 분석 가능 |
| `0100` NO DATA | CAN-H/L 뒤바뀜, GND 공통 여부, 차량 프로토콜(2008년 이후 국산차는 CAN) |
| 부팅 반복 | TP4 전압 강하 확인, USB 동시 인가 여부 |
| WiFi 약함 | 데브킷 방향(안테나가 키프아웃 쪽인지) |

결과는 이 파일에 기록해서 커밋.

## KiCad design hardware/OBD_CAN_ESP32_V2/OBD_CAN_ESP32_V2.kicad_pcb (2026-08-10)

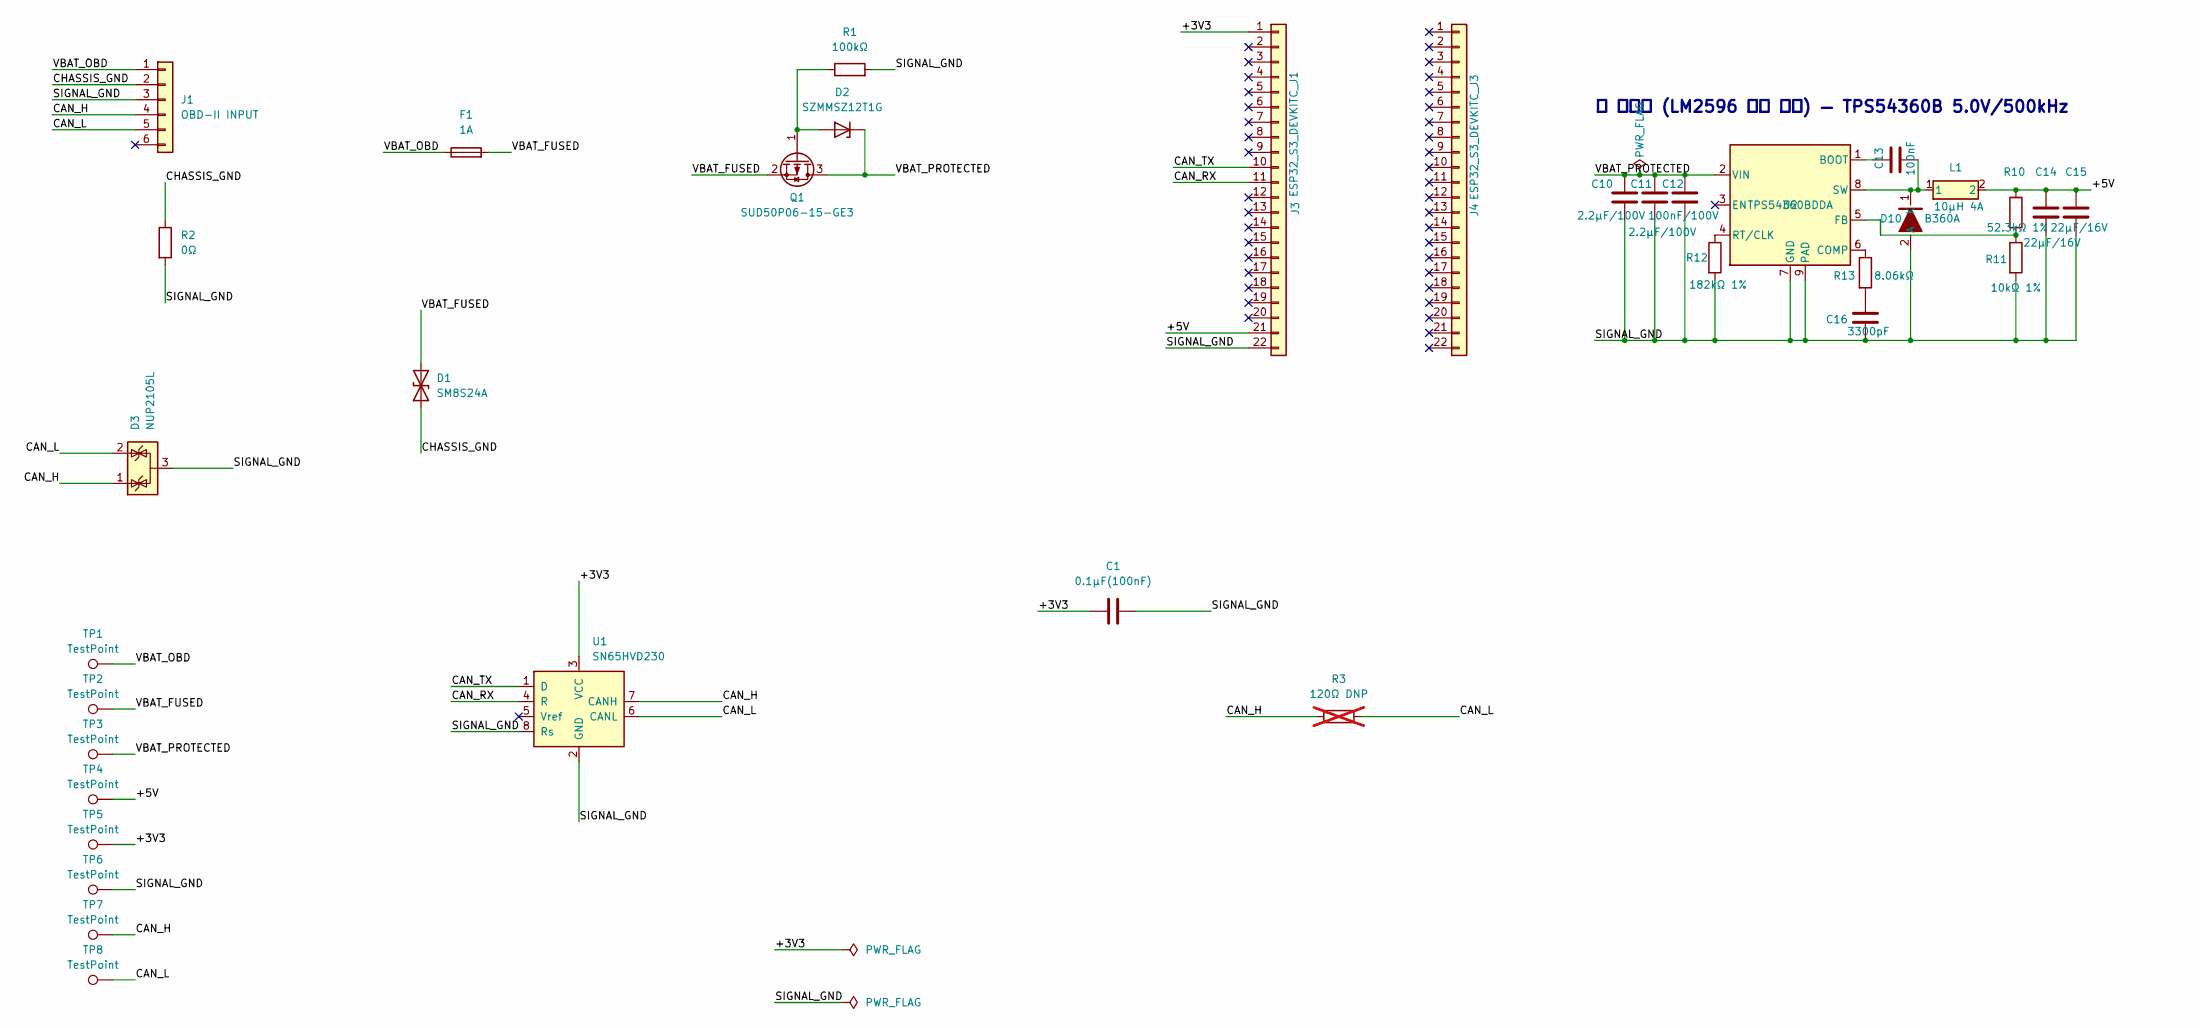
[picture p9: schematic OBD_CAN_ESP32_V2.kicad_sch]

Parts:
C1: 0.1µF(100nF); C_0805_2012Metric
C10, C11: 2.2µF/100V; C_1210_3225Metric
C12: 100nF/100V; C_0805_2012Metric
C13: 100nF; C_0603_1608Metric
C14, C15: 22µF/16V; C_1206_3216Metric
C16: 3300pF; C_0603_1608Metric
D1: SM8S24A; DO-218AB_SM8S
D2: SZMMSZ12T1G; D_SOD-123
D3: NUP2105L; SOT-23
D10: B360A; D_SMA
F1: 1A; Fuse_1812_4532Metric_Pad1.30x3.40mm_HandSolder
J1: OBD-II INPUT; JST_XH_S6B-XH-A_1x06_P2.50mm_Horizontal
J3: ESP32_S3_DEVKITC_J1; PinHeader_1x22_P2.54mm_Vertical
J4: ESP32_S3_DEVKITC_J3; PinHeader_1x22_P2.54mm_Vertical
L1: 10µH 4A; L_Sunlord_SWPA6045S
Q1: SUD50P06-15-GE3; TO-252-2
R1: 100kΩ; R_0805_2012Metric
R2: 0Ω; R_0805_2012Metric
R3: 120Ω DNP; R_0805_2012Metric; not fitted
R10: 52.3kΩ 1%; R_0603_1608Metric
R11: 10kΩ 1%; R_0603_1608Metric
R12: 182kΩ 1%; R_0603_1608Metric
R13: 8.06kΩ; R_0603_1608Metric
TP1, TP2, TP3, TP4, TP5, TP6, TP7, TP8: TestPoint; TestPoint_Pad_D2.0mm
U1: SN65HVD230; SOIC-8_3.9x4.9mm_P1.27mm
U2: TPS54360BDDA; HSOP-8-1EP_3.9x4.9mm_P1.27mm_EP2.41x3.1mm_ThermalVias

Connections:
/+3V3: C1.2, J3.1, TP5.1 (1_1), U1.3 (VCC)
/+5V: C14.1, C15.1, J3.21, L1.2, R10.1, TP4.1 (1_1)
/CAN_H: D3.1 (K), J1.4, R3.1, TP7.1 (1_1), U1.7 (CANH)
/CAN_L: D3.2 (K), J1.5, R3.2, TP8.1 (1_1), U1.6 (CANL)
/CAN_RX: J3.11, U1.4 (R)
/CAN_TX: J3.10, U1.1 (D)
/CHASSIS_GND: D1.1 (A1), J1.2, R2.1
/SIGNAL_GND: C1.1, C10.2, C11.2, C12.2, C14.2, C15.2, C16.2, D3.3 (A), D10.2 (A), J1.3, J3.22, R1.2, R2.2, R11.2, R12.2, TP6.1 (1_1), U1.2 (GND), U1.8 (Rs), U2.7 (GND), U2.9 (PAD)
/VBAT_FUSED: D1.2 (A2), F1.2, Q1.2 (S), TP2.1 (1_1)
/VBAT_OBD: F1.1, J1.1, TP1.1 (1_1)
/VBAT_PROTECTED: C10.1, C11.1, C12.1, D2.1 (K), Q1.3 (D), TP3.1 (1_1), U2.2 (VIN)
unnamed: C16.1, R13.2
unnamed: D2.2 (A), Q1.1 (G), R1.1
unnamed: C13.2, D10.1 (K), L1.1, U2.8 (SW)
unnamed: C13.1, U2.1 (BOOT)
unnamed: R13.1, U2.6 (COMP)
unnamed: R10.2, R11.1, U2.5 (FB)
unnamed: R12.1, U2.4 (RT/CLK)

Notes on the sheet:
벅 컨버터 (LM2596 모듈 대체) — TPS54360B 5.0V/500kHz

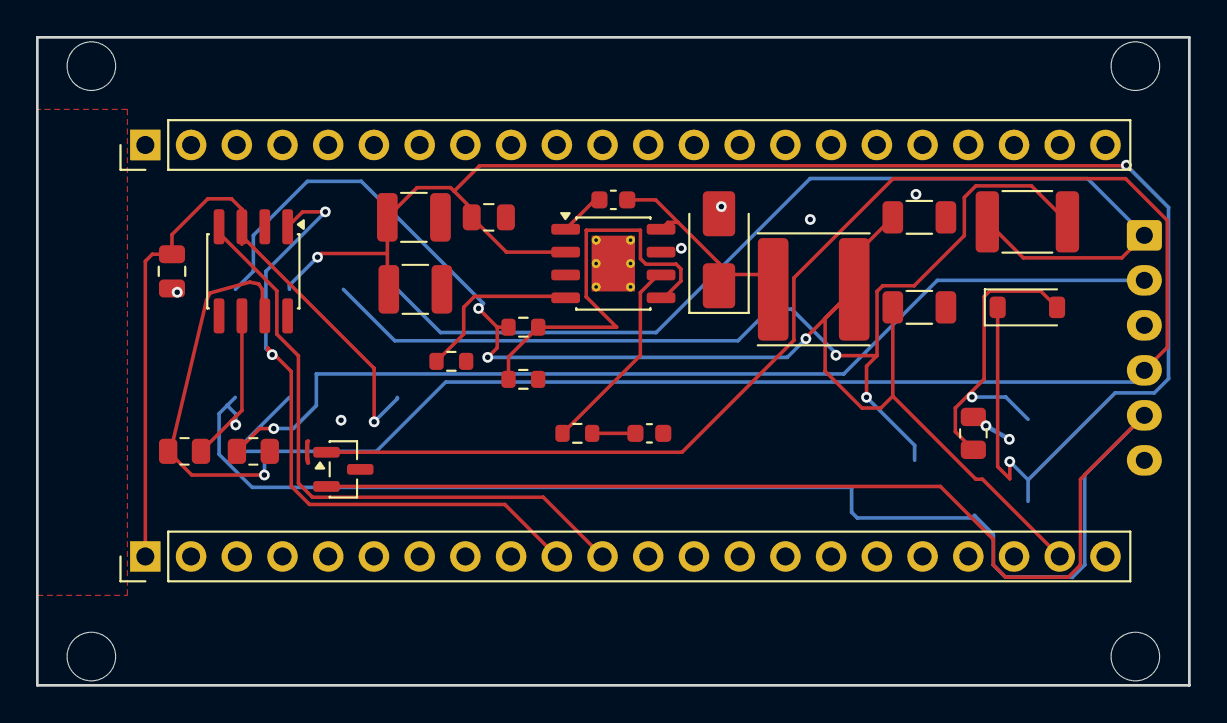
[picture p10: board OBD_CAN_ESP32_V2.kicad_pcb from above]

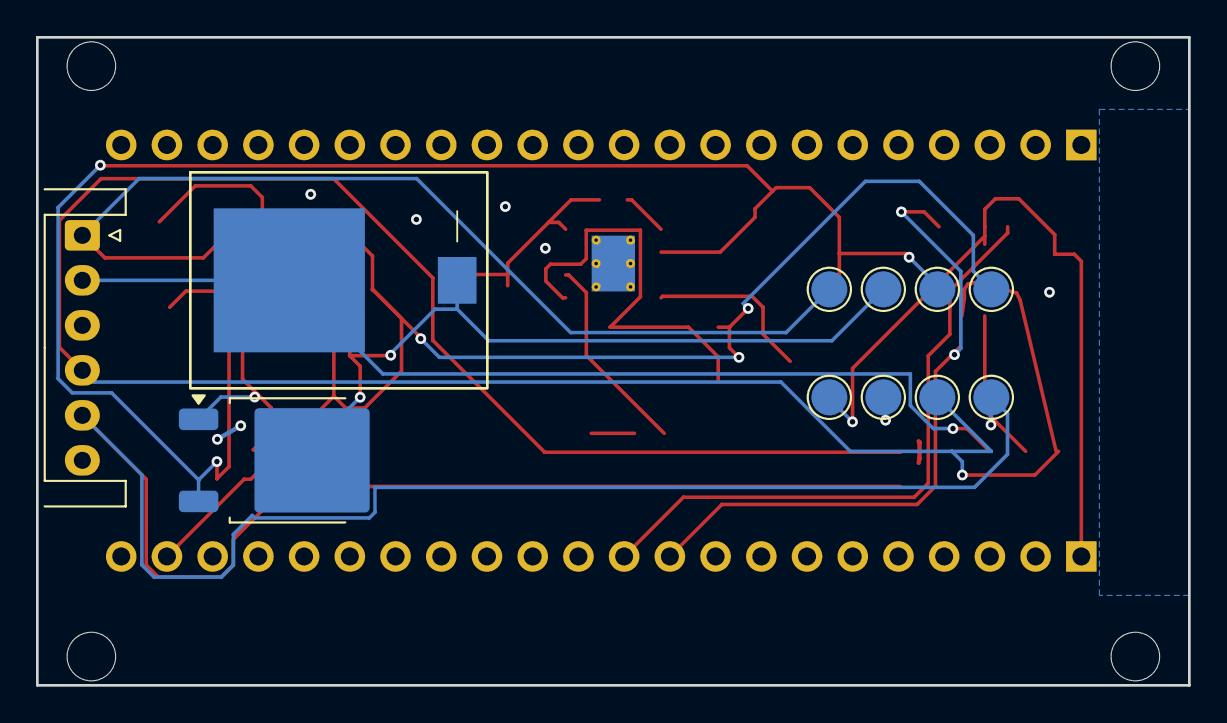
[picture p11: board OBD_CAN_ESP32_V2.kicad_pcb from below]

Board: 2 copper layers, 64.0 x 36.0 mm, 39 parts (11 on the bottom side), 18 nets.

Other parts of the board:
H1, H2, H3, H4: M2.5; MountingHole_2.7mm_M2.5

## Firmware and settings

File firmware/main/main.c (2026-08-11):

/**
 * OBD-II WiFi 게이트웨이 펌웨어 (ESP32-S3 + SN65HVD230)
 *
 * 구조:
 *   브라우저 ←WiFi/WebSocket→ [이 펌웨어: ELM327 에뮬레이션] ←TWAI(CAN)→ 차량 ECU
 *
 * 웹앱(Blazor WASM)의 WebSocketTransport와 대화 규격이 맞춰져 있다:
 *   텍스트 프레임으로 ELM327 명령 수신 → "응답\r\r>" 프레임 송신
 */
#include <stdbool.h>
#include "nvs_flash.h"
#include "esp_log.h"
#include "esp_littlefs.h"
#include "twai_bus.h"
#include "elm327.h"
#include "wifi_ap.h"
#include "ws_server.h"
#include "led_status.h"

static const char *TAG = "main";

static void mount_littlefs(void)
{
    esp_vfs_littlefs_conf_t conf = {
        .base_path = "/littlefs",
        .partition_label = "storage",
        .format_if_mount_failed = true,
    };
    esp_err_t err = esp_vfs_littlefs_register(&conf);
    if (err != ESP_OK) {
        ESP_LOGE(TAG, "LittleFS mount failed: %s", esp_err_to_name(err));
        return;
    }
    size_t total = 0, used = 0;
    esp_littlefs_info("storage", &total, &used);
    ESP_LOGI(TAG, "LittleFS: %u / %u bytes", (unsigned)used, (unsigned)total);
}

void app_main(void)
{
    // NVS (WiFi가 요구)
    esp_err_t err = nvs_flash_init();
    if (err == ESP_ERR_NVS_NO_FREE_PAGES || err == ESP_ERR_NVS_NEW_VERSION_FOUND) {
        ESP_ERROR_CHECK(nvs_flash_erase());
        ESP_ERROR_CHECK(nvs_flash_init());
    }

    led_status_init();          // 흰색: 부팅 중
    elm327_reset();
    mount_littlefs();

    ESP_ERROR_CHECK(wifi_ap_start());

    // CAN은 실패해도 서버는 띄운다 (벤치에서 트랜시버 미연결 상태 대비)
    bool can_ok = (twai_bus_start() == ESP_OK);
    if (!can_ok)
        ESP_LOGW(TAG, "TWAI start failed — OBD 요청은 NO DATA로 응답됩니다");

    ESP_ERROR_CHECK(ws_server_start());

    led_status_set(can_ok ? LED_AP_READY : LED_CAN_FAIL);

    ESP_LOGI(TAG, "준비 완료: WiFi 'OBD2-DIAG' 접속 후 http://192.168.4.1/ 접속");
}

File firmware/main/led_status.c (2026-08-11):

/**
 * ESP32-S3-DevKitC-1 내장 RGB LED(WS2812) 상태 표시
 *
 * 색 규칙:
 *   흰색        부팅 중
 *   파랑 숨쉬기  WiFi AP 준비됨 (정상 대기)
 *   초록 깜빡   ELM327 명령 처리 (통신 활동)
 *   주황        CAN(TWAI) 시작 실패
 *   보라 점멸   OTA 업데이트 진행 중
 *
 * 주의: DevKitC-1 v1.1은 GPIO38, v1.0은 GPIO48.
 * 실물에서 LED가 안 켜지면 RGB_LED_GPIO를 38로 바꿔 재빌드.
 */
#include "led_status.h"
#include "led_strip.h"
#include "esp_log.h"
#include "freertos/FreeRTOS.h"
#include "freertos/task.h"

#define RGB_LED_GPIO 48   // DevKitC-1 v1.0 = 48, v1.1 = 38
#define BRIGHT 40         // 최대 밝기 (0~255) — 눈 아프지 않게 낮춤

static const char *TAG = "led";
static led_strip_handle_t s_strip;
static volatile led_state_t s_state = LED_BOOT;
static volatile int s_activity = 0;

static void set_rgb(uint8_t r, uint8_t g, uint8_t b)
{
    if (!s_strip) return;
    led_strip_set_pixel(s_strip, 0, r, g, b);
    led_strip_refresh(s_strip);
}

static void led_task(void *arg)
{
    int t = 0;
    while (1) {
        if (s_activity > 0) {                 // 통신 활동: 초록 짧게
            s_activity--;
            set_rgb(0, BRIGHT, 0);
        } else switch (s_state) {
        case LED_BOOT:
            set_rgb(BRIGHT/2, BRIGHT/2, BRIGHT/2);
            break;
        case LED_AP_READY: {                  // 파랑 숨쉬기 (3초 주기)
            int ph = t % 60;
            int lv = ph < 30 ? ph : 60 - ph;  // 0..30 삼각파
            set_rgb(0, 0, 4 + lv * BRIGHT / 30);
            break;
        }
        case LED_CAN_FAIL:
            set_rgb(BRIGHT, BRIGHT/3, 0);     // 주황
            break;
        case LED_OTA:
            set_rgb((t & 4) ? BRIGHT : 0, 0, (t & 4) ? BRIGHT : 0);
            break;
        }
        t++;
        vTaskDelay(pdMS_TO_TICKS(50));
    }
}

void led_status_init(void)
{
    led_strip_config_t strip_cfg = {
        .strip_gpio_num = RGB_LED_GPIO,
        .max_leds = 1,
        .led_model = LED_MODEL_WS2812,
        .color_component_format = LED_STRIP_COLOR_COMPONENT_FMT_GRB,
    };
    led_strip_rmt_config_t rmt_cfg = {
        .resolution_hz = 10 * 1000 * 1000,
    };
    if (led_strip_new_rmt_device(&strip_cfg, &rmt_cfg, &s_strip) != ESP_OK) {
        ESP_LOGW(TAG, "RGB LED init failed (GPIO%d) — 상태표시 없이 계속", RGB_LED_GPIO);
        s_strip = NULL;
        return;
    }
    xTaskCreate(led_task, "led", 2048, NULL, 2, NULL);
}

void led_status_set(led_state_t s)  { s_state = s; }
void led_status_activity(void)      { s_activity = 3; }  // ~150ms 초록

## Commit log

2026-08-08 docs: OBD-II 웹 진단 시스템 프로젝트 문서 초안
    로드맵(개인용→소량검증→판매), BOM/구매처, OBD 핀맵·결선도,
    펌웨어·웹앱 아키텍처, 라이선스 전략, KC 인증 체크리스트
    Claude-Session: https://claude.ai/code/session_015Lj2iN8K2AKiUuQKmtXaeP
2026-08-08 docs: Phase 1 부품 구매 체크리스트 추가
    매장별(디바이스마트/제노몰/쿠팡) 검색 키워드·수량·확인 포인트,
    OBD 커넥터 선별 기준, ELM327 BLE 동글 가이드
    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
2026-08-08 feat: Blazor WASM 진단 웹앱 뼈대
    - 트랜스포트 추상화(IObdTransport): 시뮬레이터 / Web Bluetooth(BLE)
    - ELM327 클라이언트(초기화 시퀀스, 명령 큐, 타임아웃)
    - SAE J1979 Mode 01 PID 디코더, DTC 파서(한글 설명), VIN 조회
    - 가상 ECU 시뮬레이터로 엔드투엔드 스모크 테스트 통과
    - 대시보드 UI: 연결 패널, 실시간 게이지, DTC 조회/2단계 소거, 통신 로그
    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
2026-08-08 ci: GitHub Pages 자동 배포 워크플로 추가
    main 푸시 시 Blazor WASM publish → base href 재작성 → Pages 배포
    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
2026-08-08 ci: Pages 배포 재실행 트리거
    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
2026-08-08 feat: PWA 구성 및 앱 아이콘 추가
    - manifest.webmanifest + 서비스 워커(오프라인 캐싱, 배포 빌드 전용)
    - 설치형 앱 지원: 홈 화면 추가 후 인터넷 없이 실행 가능
    - 게이지 모티브 앱 아이콘 (512/192/favicon)
    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
2026-08-08 style: 대시보드 밀도 상향 (여백/폰트 축소)
    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
2026-08-08 refactor: MVVM 구조로 재편
    - Models/ 분리: VehicleSnapshot, DiagnosticTroubleCode, PidDefinitions
    - ViewModels/DashboardViewModel: INotifyPropertyChanged 기반 화면 상태·커맨드 소유
    - Home.razor는 바인딩 전용 뷰로 축소 (PropertyChanged → StateHasChanged)
    - 시뮬레이터 스모크 테스트 재통과
    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
2026-08-08 feat: ESP32 펌웨어 골격 + 웹앱 WebSocket 트랜스포트
    firmware/ (ESP-IDF 5.x, ESP32-S3):
    - TWAI 드라이버 (500kbps, GPIO4/5, 0x7E8~0x7EF 수신 필터)
    - ISO-TP 최소 구현 (SF 요청, FF+CF 멀티프레임 조립, Flow Control)
    - ELM327 호환 명령 파서 (웹앱 시뮬레이터와 동일 대화 규격)
    - WiFi SoftAP(OBD2-DIAG) + WebSocket(/ws) + LittleFS 정적 서빙
    - 내장 벤치 테스트 콘솔 (http://192.168.4.1/)
    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
    [partitions.csv]
2026-08-08 design: 대시보드 전문 디자인 개편 + 기기 자동 감지 연결
    - 검증된 다크 데이터비주얼 팔레트를 디자인 토큰으로 도입 (표면/잉크/상태 색 체계)
    - RPM 히어로 수치 + PID별 스파크라인(선 muted, 현재값만 액센트)
    - 냉각수온/연료/부하/스로틀 심각도 미터 (트랙=동일 램프 어두운 스텝)
    - DTC 상태 도트(아이콘+라벨) 규격, 통신 로그 접이식
    - 3모드 선택 제거 → Web Bluetooth 지원 감지로 자동 선택 (iPhone→WiFi 보드),
    수동 변경은 컴팩트 드롭다운
    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
2026-08-08 fix: Razor 지시 특성 값 명시 (@onclick:stopPropagation)
    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
2026-08-08 fix: Razor 식과 한글 텍스트 분리 (@(Vm.Log.Count)건)
    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
2026-08-08 docs: 벤치 검증 절차서 추가 (5단계 + 트러블슈팅)
    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
2026-08-08 fix: 서비스 워커 등록에 보안 컨텍스트 가드 (ESP32 self-hosting 대비)
    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
2026-08-09 docs: 벤치 조립 회로도 추가 (주문 부품 모듈 단위, SVG)
    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
2026-08-09 docs: 만능기판 배치도 + 배선표 추가 (6x8cm, 14단계 배선 순서)
    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
2026-08-09 docs: 초보자용 실물 배선 가이드 추가 (3단계 그림)
    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
2026-08-09 hardware: KiCad 회로도 추가 (벤치 회로, 심볼 내장, kicad-cli 검증)
    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
    [obd2-gateway.kicad_sch]
2026-08-09 hardware: 회로도를 배선(wire) 방식으로 재작성 (Rev B, 초보자 가독성)
    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
    [obd2-gateway.kicad_sch]
2026-08-10 feat: PCB V2 계획(C안) + TWAI 핀 GPIO17/18 통일
    - docs/pcb-v2-plan.md: TPS54360B 벅 회로(BOM/값), 66x36 배치 계획, V1 수정사항
    - docs/pcb-v2-placement.svg: 존 배치 계획도
    - 펌웨어·문서·회로도 전체 GPIO4/5 → GPIO17/18 (사용자 PCB J3 핀10/11 기준)
    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
    [obd2-gateway.kicad_sch]
2026-08-10 hardware: 사용자 KiCad 프로젝트 V2 (C안 반영)
    - D2 제너 180° 회전 (극성 수정)
    - J2(LM2596 모듈) 삭제, TPS54360B 벅 회로 추가 (부품값/풋프린트 포함)
    - J1 풋프린트 → JST-XH 6P
    - PCB 외곽 69x72 → 66x36, 부품 존별 재배치, 용지 A3
    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
    [OBD_CAN_ESP32_V2.kicad_pcb, OBD_CAN_ESP32_V2.kicad_sch]
2026-08-10 hardware: V2 재작성 — 기존 라우팅/존 정리, 헤더 원점 수정
    - V1의 트랙 97개 삭제(재배치로 무효), 구리 존 2개는 새 외곽으로 재정의
    - 데브킷 헤더 원점을 좌측(61mm)으로 — 핀이 보드 안쪽으로 뻗도록
    - 별도 폴더 OBD_CAN_ESP32_V2로 분리
    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
    [OBD_CAN_ESP32_V2.kicad_pcb]
2026-08-10 hardware: V2 ERC 수정 — 고아 배선 4개 삭제, VBAT_PROTECTED에 PWR_FLAG 추가
    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
    [OBD_CAN_ESP32_V2.kicad_sch]
2026-08-10 hardware: V2 ERC 수정 재적용 (KiCad 재저장으로 유실된 수정 복원)
    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
    [OBD_CAN_ESP32_V2.kicad_sch]
2026-08-10 hardware: V2 라이브러리 등록 + 풋프린트 확정 (SWPA6045S, HSOP-8 ThermalVias)
    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
    [OBD_CAN_ESP32_V2.kicad_sch]
2026-08-10 hardware: V2 PCB 66x44 부품 배치 완료 (옵션2, 겹침 0 검증)
    - 보드 66x36 → 66x44 (D1 SM8S24A 대형 TVS 수용)
    - 존 배치: CAN(좌)/벅(중앙)/입력보호(하단)/커넥터+TP(최하단)
    - 자체 커트야드 겹침 검사 통과 (겹침 0, 외곽 초과 0)
    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
    [OBD_CAN_ESP32_V2.kicad_pcb]
2026-08-10 hardware: V2 66x36 양면 배치 + M2.5 나사구멍 4개
    - 보드 66x44 → 66x36 복원 (D1/Q1 뒷면 이설 전제)
    - 앞면 부품 재배치, 겹침 0 검증
    - 네 모서리 M2.5 마운팅홀(H1~H4) 추가 (케이스 고정용)
    - D1/Q1은 뒷면 전환 대기 (사용자가 KiCad F키로 전환)
    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
    [OBD_CAN_ESP32_V2.kicad_pcb]
2026-08-10 hardware: V2 최소화 61.5x30 (TP·OBD커넥터도 뒷면 이설 전제)
    - 보드 66x36 → 61.5x30 (데브킷 그림자 수준, 면적 -22%)
    - 앞면=소형 SMD만, 뒷면 이설 대기: D1/Q1/J1/TP1~8
    - M2.5 나사구멍 4개 재배치(헤더 핀 간섭 없이 코너)
    - 겹침 0 검증
    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
    [OBD_CAN_ESP32_V2.kicad_pcb]
2026-08-10 hardware: V2 64x31 재배치 — 커트야드 기준 자동 간격분리 (겹침 0)
    - 보드 61.5x30 → 64x31 (나사구멍·헤더 간격 여유)
    - 앞면 SMD 커트야드 겹침 0, 헤더행/나사구멍 침범 0 (자동 분리 알고리즘)
    - 뒷면(D1/Q1/J1/TP) 사용자 배치 보존
    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
    [OBD_CAN_ESP32_V2.kicad_pcb]
2026-08-10 hardware: V2 64x36 최종 — 나사구멍 헤더 밖 배치 + 최소홀 0.2mm
    - 보드 64x31 → 64x36 (헤더 위/아래 여백 확보)
    - 나사구멍 4개를 헤더 커트야드 밖 상하 코너로 (겹침 0)
    - 보드 최소 through-hole 0.3 → 0.2mm (U2 TPS54360B 열패드 방열비아 12개 허용, JLCPCB 지원)
    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
    [OBD_CAN_ESP32_V2.kicad_pcb]
2026-08-10 V2 PCB: Freerouting 자동배선 세션(.ses) 추가 — 17넷 전체 배선 완료
    [OBD_CAN_ESP32_V2.dsn]
2026-08-10 V2 PCB 배선 완료: 자동배선 + 미연결 13건 전량 수정 (GND 존 솔리드 연결, 스티칭 비아 8, D1 패드 정규화)
    [OBD_CAN_ESP32_V2.kicad_pcb]
2026-08-10 V2 PCB: 배선 완료 (오류 0/미연결 0) + 끊긴 배선 꼬리 6개 정리
    [OBD_CAN_ESP32_V2.kicad_pcb]
2026-08-10 V2 PCB 경고 정리: refdes를 Fab 레이어로, J1 실크 클리핑, 죽은 배선 제거, D1 풋프린트 정규화 + 조립도면 추가
    [OBD_CAN_ESP32_V2.kicad_pcb]
2026-08-10 발주 패키지 추가: 거버/드릴/BOM(LCSC)/CPL + 발주 안내서
    [BOM-jlcpcb.csv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]
2026-08-10 안테나 구리 금지 영역 추가 (x55-60/y92-119 양면) + Q1 = SUD50P06-15-GE3 확정
    [OBD_CAN_ESP32_V2.kicad_pcb, OBD_CAN_ESP32_V2.kicad_sch]
2026-08-10 거버 재출력: 안테나 키프아웃 반영판으로 발주 패키지 갱신 (+페이스트 레이어)
    [OBD_CAN_ESP32_V2-B_Cu.gbr, OBD_CAN_ESP32_V2-B_Mask.gbr, OBD_CAN_ESP32_V2-B_Paste.gbr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]
2026-08-10 펌웨어: DevKitC-1-N8R8용 파티션(3M app + 4M littlefs) 및 8MB 플래시 설정
    [partitions.csv]
2026-08-11 벤치 절차서를 V2 완성보드 첫 통전 절차로 개정 (TP 기반 단계 검증)
2026-08-11 OTA 펌웨어 업데이트 추가: 듀얼 앱 파티션(ota_0/ota_1) + POST /ota 핸들러 + 콘솔 업로드 UI
    [partitions.csv]
2026-08-11 IDF v6 호환: esp_timer 의존성 추가 + 구형 TWAI deprecation 경고 완화
2026-08-11 3D 프린팅 케이스 초안 v1 (파라메트릭 OpenSCAD + STL)
    [obd2_case.scad, obd2_case_base.stl, obd2_case_lid.stl]
2026-08-11 데브킷 내장 RGB LED 상태표시: 부팅(흰색)/AP대기(파랑 숨쉬기)/통신(초록)/CAN실패(주황)/OTA(보라)
2026-08-11 케이스: RGB LED 상태표시 창 추가 (원뿔형 ⌀5, 위치 파라메트릭)
    [obd2_case.scad, obd2_case_lid.stl]
